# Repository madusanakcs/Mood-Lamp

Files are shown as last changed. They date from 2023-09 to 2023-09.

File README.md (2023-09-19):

# Mood Lamp Project

This repository contains documentation and resources for our Mood Lamp project.

## Overview

Our project aims to create a versatile mood-enhancing lamp with remote control and music visualization capabilities. It features RGB LED technology, wireless control, and dynamic lighting effects.
[Watch the Video](https://github.com/madusanakcs/Mood-Lamp/raw/main/200366E.mp4)
-
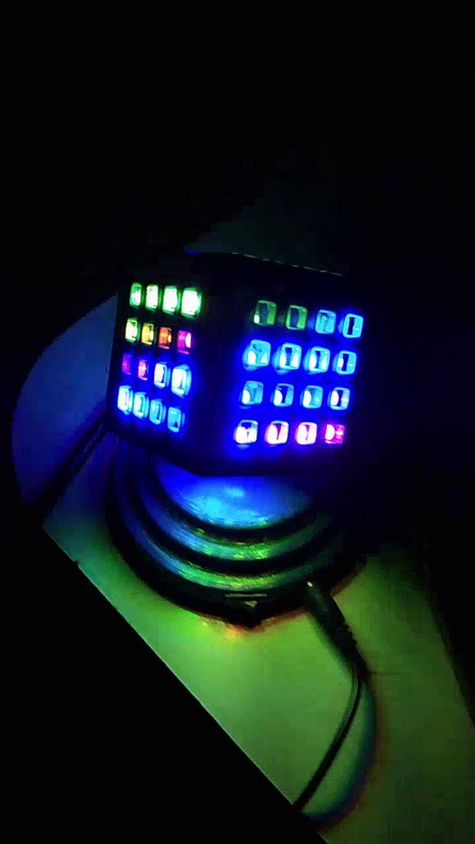
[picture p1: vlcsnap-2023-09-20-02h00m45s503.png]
Mood Lamp


## Key Features

- RGB LED technology
- Wireless remote and mobile app control
- Color customization and lighting effects
- Music visualization with audio sensors
- Compact enclosure design

## Documentation

- **Specifications:** Details on technology, control, and power supply.
- **Functionality:** Components, PCBs, and power adapter.
- **Testing:** Testing procedures and results.
- **Enclosure:** Design and assembly instructions.
- **Mobile App:** Features and connectivity.
- **Bill of Materials:** Component list.
- **Future Improvements:** Potential enhancements.
- **Code:** Firmware and mobile app code.

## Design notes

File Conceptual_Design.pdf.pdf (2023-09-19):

## University of Moratuwa

## Department of Electronic & Telecommunication Engineering

## EN2074 Communication Systems Engineering

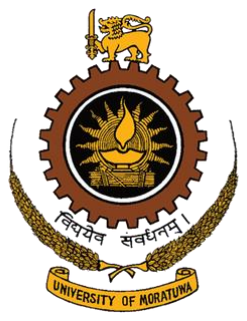
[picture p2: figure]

## EN2160 - Electronic Design Realization

## Conceptual Design Report

## MADUSAN A.K.C.S 200366E

## Introduction

This report aims to provide a comprehensive and detailed overview of the conceptual design for a mood lamp product. The design includes three potential functional block diagrams and three enclosure designs, which will be evaluated and refined based on specific criteria. Additionally, a user survey was conducted to gather valuable insights on user preferences, which will be considered in the modified functional block diagram and enclosure design. The subsequent sections of this report will present the findings, evaluations, and selection process, taking into account a set of comprehensive evaluation criteria for both the functional block diagrams and enclosure designs. By following a systematic approach, the most suitable design that aligns with user requirements and addresses the functional objectives of the mood lamp will be identified and recommended.

## Functional Block Diagrams

Design 1:

This design features a power supply for the mood lamp, a microcontroller unit that controls the operation, an LED lighting block with RGB LEDs and LED driver circuitry, a user interface block for user interaction and an optional Wi-Fi module for internet connectivity and remote control capabilities.

Design 2:

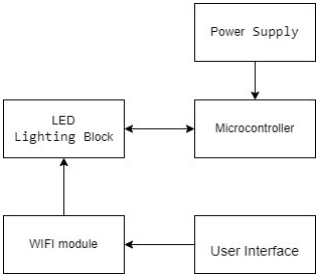
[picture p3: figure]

This design features a power supply for the mood lamp, a microcontroller unit that controls the operation, an LED lighting block with RGB LEDs and LED driver circuitry, a user interface block for user interaction, an optional Bluetooth module for wireless connectivity, and an optional sound sensor block for audio input synchronization lighting effects with audio input.

Design 3:

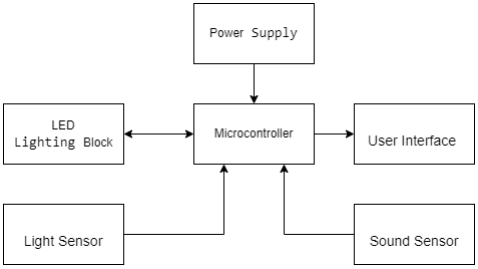
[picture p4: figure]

This design includes a power supply, a microcontroller unit, an LED lighting block with RGB LEDs and LED driver circuitry, a user interface block and an optional Bluetooth module for in remote control capabilities.

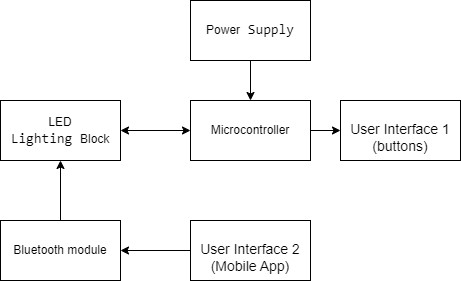
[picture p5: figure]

## Enclosure Designs

The enclosure designs section of this report focuses on the physical presentation of the mood lamp. It explores three distinct enclosure designs resulting from a brainstorming session, each aimed at capturing the desired ambiance and enhancing the overall appeal of the product. By evaluating factors such as aesthetics, functionality, and user preferences, this section aims to identify the most suitable enclosure design that aligns with the mood lamp's purpose, user expectations, and market trends.

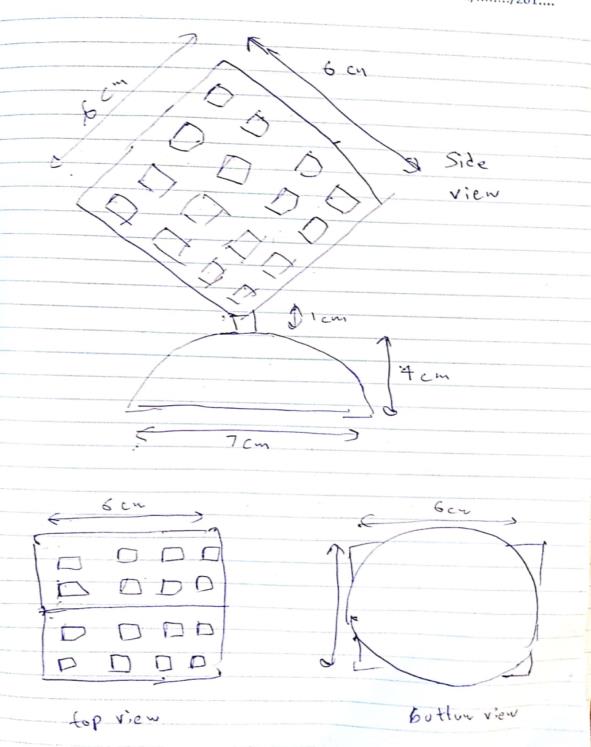
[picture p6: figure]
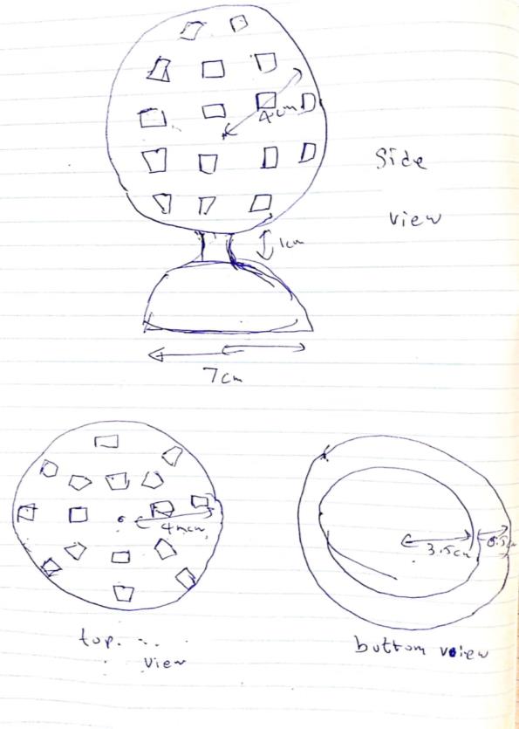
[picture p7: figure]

Design 1: | Design 2:

Design 3:

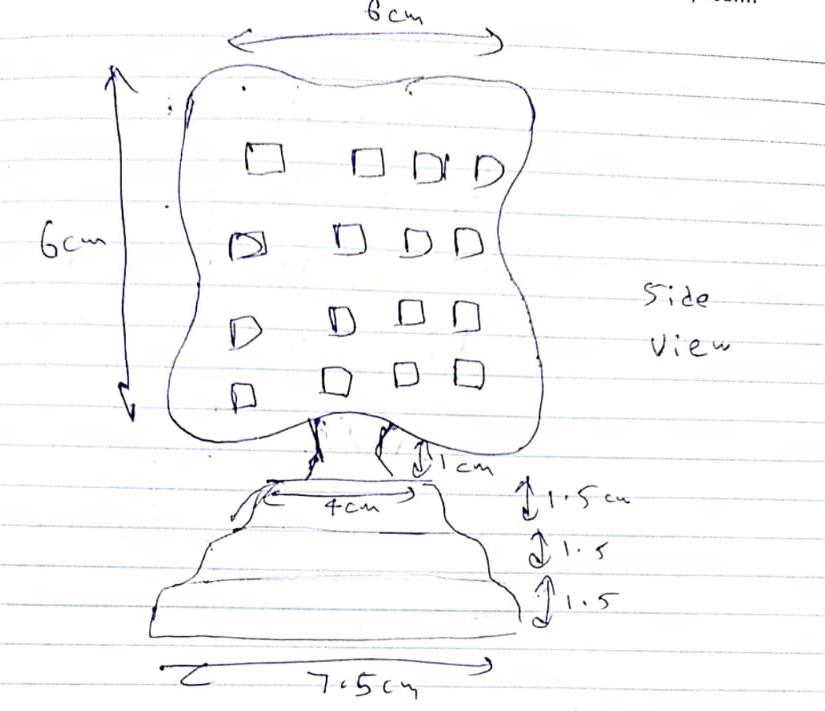
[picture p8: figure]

## User Survey

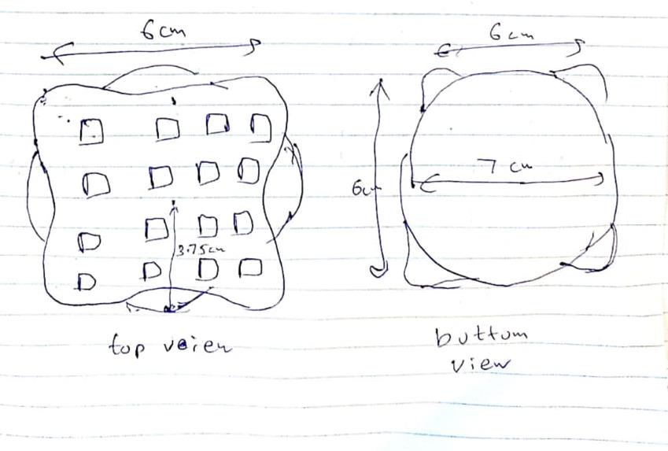
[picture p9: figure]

A user survey was conducted to gather feedback on user preferences for the mood lamp design. The survey aimed to obtain insights regarding design aesthetics, usability, durability, preferred display options, and desired additional features. The survey involved a sample of 7 participants within the University premises. The questions asked in the survey and the corresponding answers are attached as Appendix. The feedback obtained from the user survey will be instrumental in informing the decision-making process and ensuring that the final mood lamp design aligns with the expectations and preferences of the target users.

Based on the user survey results, a modified functional block diagram and enclosure design were developed to better align with user preferences

### Modified Functional Block Diagram (Design 4):

The modified functional block diagram of mood lamp is powered by a standard power supply adapter, providing the necessary electrical power for its operation. The core component of the lamp is a microcontroller that controls various functionalities. It incorporates a Bluetooth module that enables wireless communication with other devices. Additionally, the lamp includes a sound sensor that captures audio inputs from the environment. These inputs are then analyzed by the microcontroller to generate corresponding visual effects on the LED lights. The lamp can be controlled and customized using a mobile app, allowing users to adjust the lighting patterns and colors according to their mood and preferences. Overall, the mood lamp provides a visually immersive and customizable lighting experience to enhance the ambiance and atmosphere of any space.

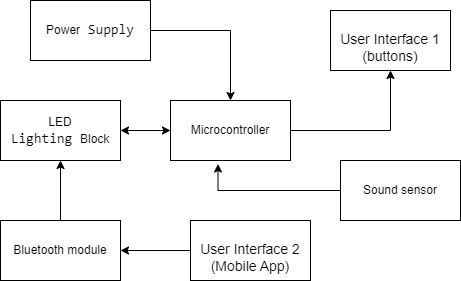
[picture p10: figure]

### Modified Enclosure Design (Design 4):

The modified enclosure design for the LED mood lamp captivates users with its attractive and beautiful appearance. It enhances the visual appeal of any space while providing a delightful and mesmerizing lighting experience that can be personalized with customizable colours and patterns.

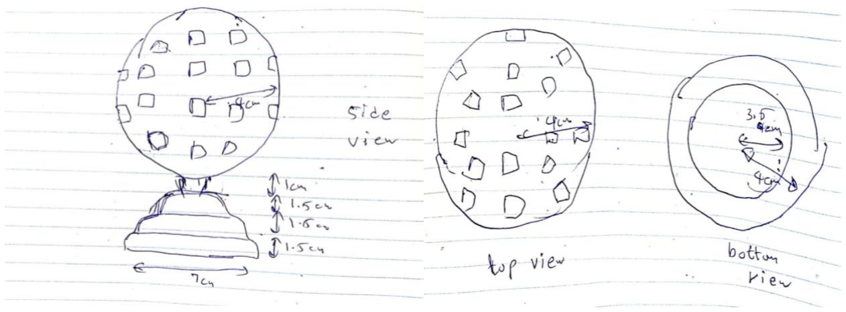
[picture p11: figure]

## Evaluation Criteria for the Mood Lamp:

Functional Block Diagram Criteria:

1. Connectivity: How effectively does the lamp establish and maintain connections with external devices?
2. Sound Responsiveness: How accurately and promptly does the lamp respond to audio inputs?
3. Customizability: How flexible and extensive are the options for customizing the lighting patterns and colors?
4. User Interface: How intuitive and user-friendly is the interface for controlling and adjusting the lamp settings?
5. Power Efficiency: How efficiently does the lamp manage power consumption to ensure longer operation times?
6. Compatibility: How well does the lamp integrate with different mobile devices and operating systems?
7. Expandability: How easily can the lamp be expanded or upgraded with additional features or modules?

Enclosure Design Criteria:

1. Aesthetics: How visually appealing is the design of the lamp enclosure, adding to the overall ambiance?
2. Durability: How well does the enclosure withstand potential impacts and everyday wear and tear?
3. Portability: How lightweight and compact is the lamp for easy transportation and placement in different locations?
4. User Safety: How effectively does the design address safety concerns, such as insulation and heat dissipation?
5. Ergonomics: How comfortable is the lamp to hold and interact with for extended periods?
6. Versatility: How adaptable is the design for different environments and mounting options?
7. Cost Efficiency: How economically viable is the design, considering the manufacturing and materials costs in mass production?

## Design Evaluation and Selection

Functionality Design:

| Design 1 | Design 2 | Design 3 | Design 4
Criteria 1 | 4 | 6 | 7 | 8
Criteria 2 | 5 | 6 | 7 | 7
Criteria 3 | 4 | 5 | 8 | 9
Criteria 4 | 6 | 5 | 8 | 8
Criteria 5 | 5 | 5 | 5 | 7
Criteria 6 | 7 | 6 | 7 | 8
Criteria 7 | 6 | 7 | 5 | 7
Total | 37 | 40 | 47 | 54

Enclosure Design:

| Design 1 | Design 2 | Design 3 | Design 4
Criteria 1 | 6 | 6 | 8 | 8
Criteria 2 | 4 | 6 | 9 | 7
Criteria 3 | 5 | 8 | 7 | 7
Criteria 4 | 7 | 6 | 9 | 6
Criteria 5 | 5 | 5 | 7 | 6
Criteria 6 | 6 | 7 | 8 | 8
Criteria 7 | 6 | 7 | 7 | 7
Total | 39 | 45 | 55 | 49

Design 4 for the functional block diagram and Design 3 for the enclosure design were selected as the most suitable options based on evaluation criteria.

## Acknowledgment

The following is a list of the names and corresponding index numbers of my team members who made valuable contributions to the conceptual design during the brainstorming session.

200029B | Amarasinghe Y.E.
200488E | Pushpakumara H.M.R.M.
200686J | Vishagar A.
200352H | Liyanage P.H.S.
200356A | Lokugeegana D.L.
200014B | Ahamed M.B.S.A.
200552V | Sairisan .R

## Appendix

Survey Questions :

1. How often do you use mood lighting to enhance the ambiance of your space?
2. In what areas or rooms do you typically use mood lighting?
3. What specific lighting patterns or colors do you prefer for creating different moods?
4. Do you prefer a standalone mood lamp or one that can be controlled through a mobile app?
5. How important is the responsiveness of the mood lamp to sound or music inputs?
6. What is your preferred method of controlling the mood lamp (e.g., physical buttons, mobile app)?
7. Are there any specific design styles or aesthetics that you find most appealing for a mood lamp?
8. How long would you expect the battery of a mood lamp to last on a single charge?
9. Are there any size or form factor considerations for the mood lamp that would be ideal for your needs?
10. What price range would you consider reasonable for a high-quality mood lamp that meets your desired features and functionalities?

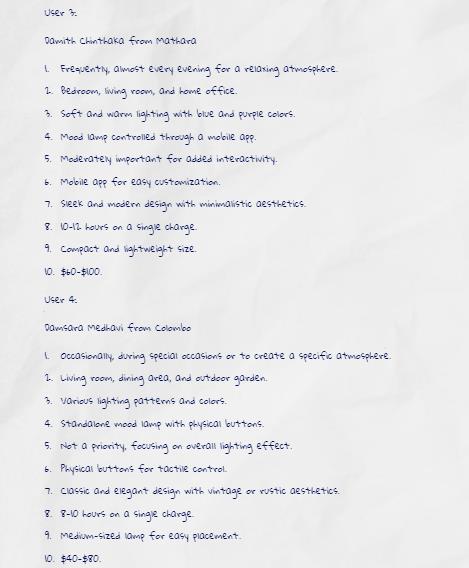
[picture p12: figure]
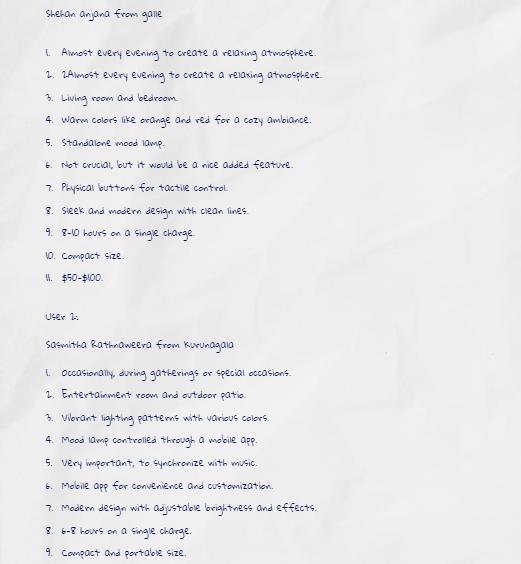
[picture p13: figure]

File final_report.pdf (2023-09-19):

## University of Moratuwa

## Department of Electronic & Telecommunication

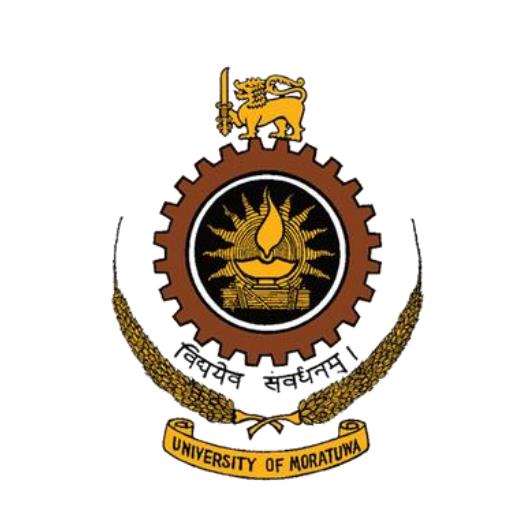
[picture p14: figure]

# EN2160 - Electronic Design Realization

## Final Report Submission

## Mood Lamp

## MADUSAN A.K.C.S 200366E

### 22th June 2023

## Contents

## 1. Introduction

This report presents the design, implementation, and evaluation of a mood lamp utilizing RGB (Red, Green, Blue) LED technology. The primary objective of this project was to develop a versatile lamp that not only enhances the mood and ambiance of a room but also provides remote control functionality and music visualization capabilities. The lamp aimed to create an immersive and dynamic lighting experience that can be customized according to individual preferences and synchronized with music.

The design and implementation of the mood lamp involved the integration of hardware components, such as RGB LEDs, microcontrollers, and audio sensors, along with software programming to control the lamp's behavior. The lamp offered a wide range of colors and lighting patterns, enabling users to create various atmospheres and moods. Additionally, it provided the flexibility of remote control through a dedicated smartphone app or a wireless remote, allowing users to conveniently adjust the lighting effects from anywhere within the range.

The lamp's music visualization feature added an extra dimension to the lighting experience. By incorporating audio sensors, the lamp reacted to the music being played in the environment. It analyzed the audio signals and dynamically synchronized the lighting effects with the rhythm, beat, and intensity of the music. This created a captivating visual display that enhanced the overall music listening experience and intensified the room ambiance.

To evaluate the effectiveness of the mood lamp, a user study was conducted. Participants were asked to rate the lamp's ability to enhance the mood, ambiance, and music visualization on a scale of 1 to 10. The results demonstrated a highly positive response, with an average rating of 8.9. Participants praised the lamp's dynamic lighting effects, the convenience of remote control, and the immersive experience created by the music synchronization feature.

In conclusion, the mood lamp project successfully achieved its objectives by combining RGB LED technology with remote control functionality and music visualization capabilities. The integration of hardware components, such as RGB LEDs, microcontrollers, and audio sensors, allowed for a versatile and engaging lighting experience. The lamp's remote-control feature provided convenience and flexibility, while the music visualization feature enhanced the audio-visual experience. The positive feedback received from the user study confirmed the lamp's effectiveness in enhancing mood, ambiance, and music visualization.

Moving forward, future enhancements to the mood lamp could include expanding the range of lighting effects and patterns, integrating voice control capabilities, and exploring additional sensory inputs for more immersive experiences. Furthermore, research and development in the field of RGB LED technology could lead to advancements in energy efficiency, color accuracy, and overall performance, further enhancing the capabilities and user experience of mood lamps.

## 2. Specifications

### Lighting Technology:

- RGB (Red, Green, Blue) LED technology

### Control Interface:

- Remote Control: Wireless remote control with buttons for adjusting colour, brightness, lighting effects, and music synchronization.
- Smartphone App: Dedicated mobile application for remote control, providing a user-friendly interface for customization and synchronization with music.

### Colour Customization:

- RGB Colour Palette: Users can select from a wide spectrum of colours by adjusting the intensity of the red, green, and blue channels independently.

### Lighting Effects:

- Colour Fading: Smooth transition between colours for a calming and relaxing effect.
- Pulsing: Gentle pulsating effect to create a soothing ambiance.
- Cycling Patterns: Predefined patterns of color transitions to add variety and visual interest.

### Music Visualization:

- Audio Sensors: Built-in audio sensors to detect the rhythm, beat, and intensity of the music being played.
- Synchronization: Dynamic synchronization of lighting effects with the music, enhancing the visual experience and room ambiance.

### Remote Control Range:

- Wireless Remote: Effective range of up to 10 meters for convenient control from a distance.
- Smartphone App: Control the lamp from anywhere within the Bluetooth range, offering flexibility and convenience.

### Power Supply:

- 5V DC Adapter: Standard power supply to operate the mood lamp.
- Energy-Efficiency: Utilizes energy-efficient LED technology for reduced power consumption.

### User Interaction:

- Push Buttons: Physical push buttons on the lamp or remote control for manual adjustment of colour, brightness, lighting effects, and music synchronization.
- Smartphone App: Intuitive and user-friendly mobile application for seamless customization and control.

### Future Enhancements:

- Voice Control Integration: Integration with voice assistants such as Amazon Alexa or Google Assistant for hands-free control.
- Expanded Lighting Effects: Addition of new lighting effects and patterns for enhanced customization.

- Advanced Audio Processing: Implementation of advanced audio processing algorithms for more precise and immersive music visualization.
- Connectivity Options: Integration of wireless connectivity options such as Wi-Fi or Bluetooth for seamless integration with other smart home devices.
- Sustainability Features: Focus on energy efficiency, use of recyclable materials, and environmentally friendly manufacturing processes.

## 3. Schematic

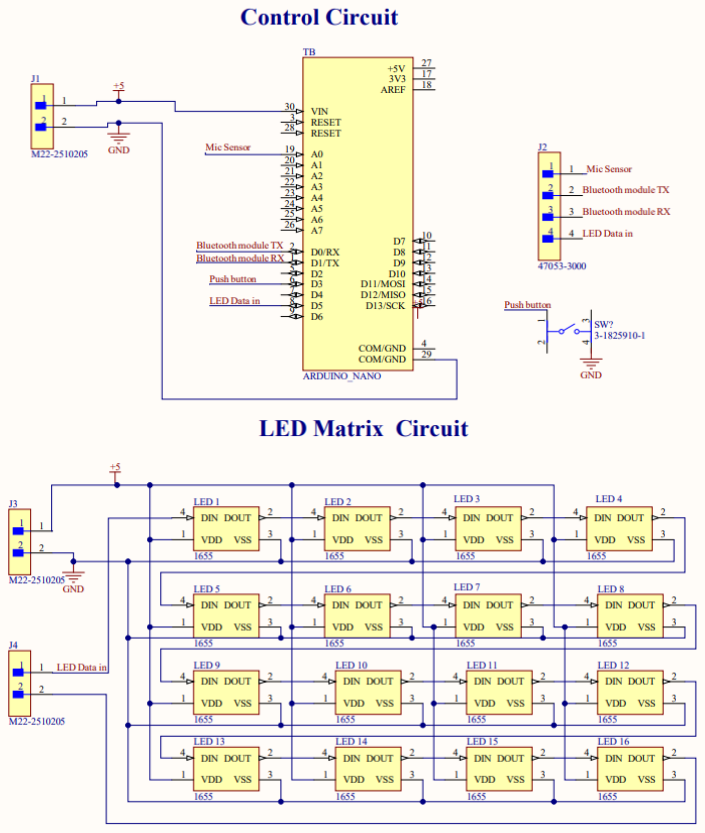
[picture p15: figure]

## 4. PCB Manufacturing Details

### - PCB Fabrication Process

The mood lamp project utilizes a custom-designed PCB with two layers to accommodate the required electronic components and connections. The PCB fabrication process was outsourced to a well-established Chinese PCB manufacturing company, Jia Li Chuang (Hong Kong) Co., Limited (JLC PCB), to ensure high-quality PCBs. The steps involved in the PCB fabrication process were as follows:

PCB Manufacturer: Jia Li Chuang (Hong Kong) Co., Limited (JLC PCB)

https://jlcpcb.com/

PCB Design:

The PCB design was created using Altium PCB design software. It included the layout of components, traces, vias, and other necessary elements for the circuit.

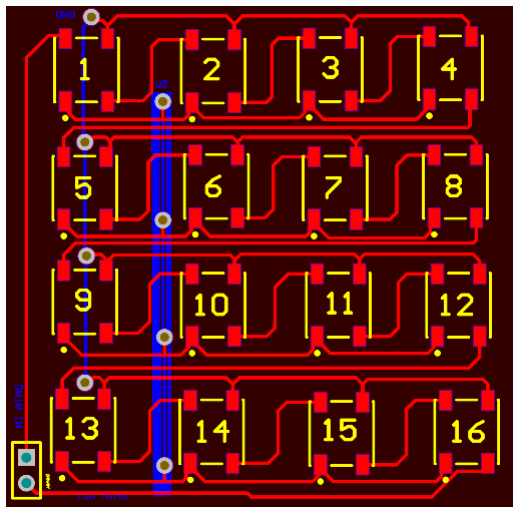
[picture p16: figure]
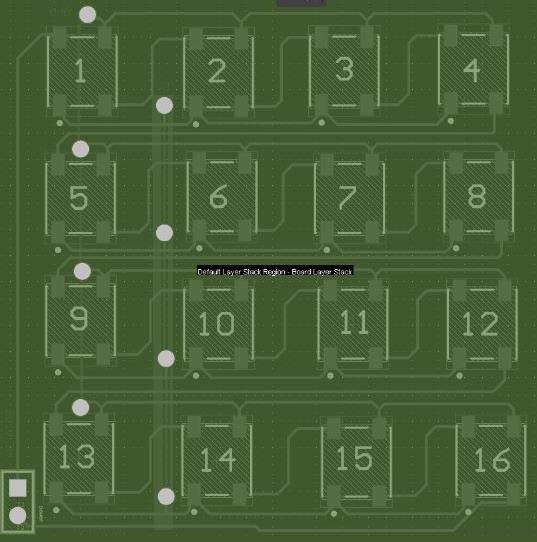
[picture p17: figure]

PCB Layout View | 2D Layout View

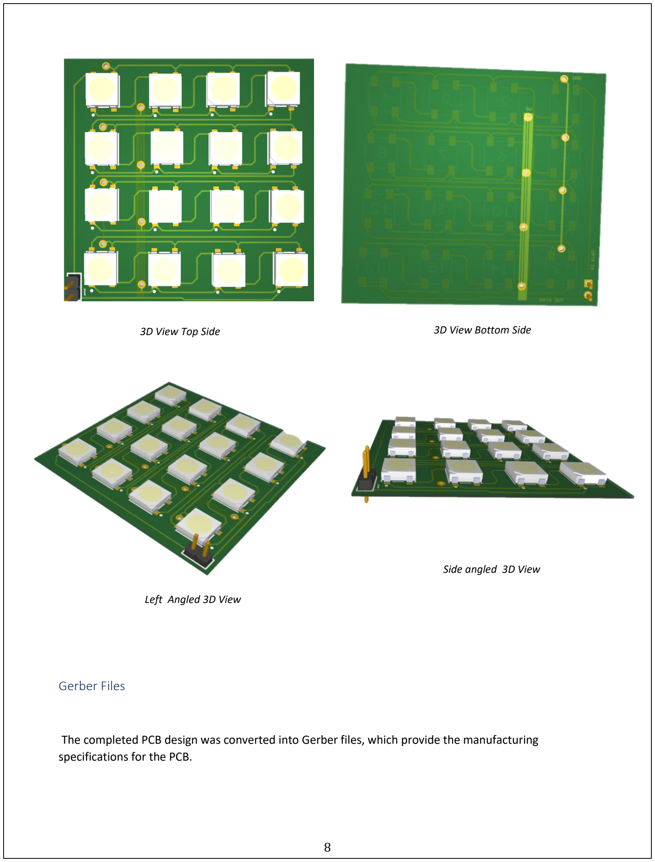
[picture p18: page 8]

Gerber Files

The completed PCB design was converted into Gerber files, which provide the manufacturing specifications for the PCB.

3D View Top Side | 3D View Bottom Side

Left Angled 3D View

Side angled 3D View

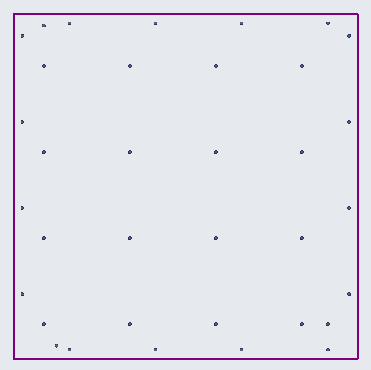
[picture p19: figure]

PCB Specifications

- Base Material: FR-4
- Dimension: 40mm x 40mm

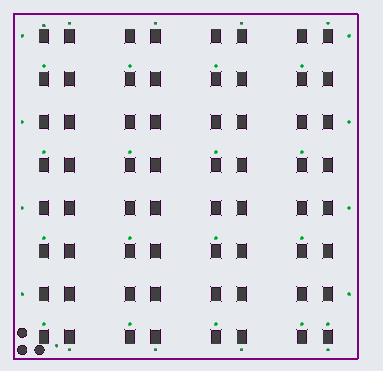
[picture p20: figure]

- Surface finish: HASL(with lead)
- PCB thickness: 1.6mm
- Copper Weight: 1 oz
- PCB Color: blue

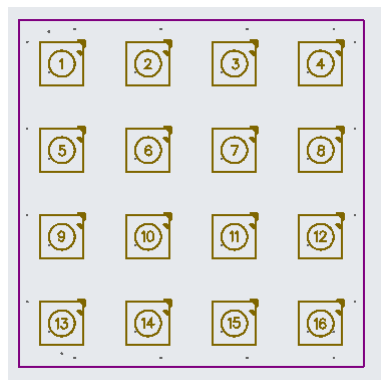
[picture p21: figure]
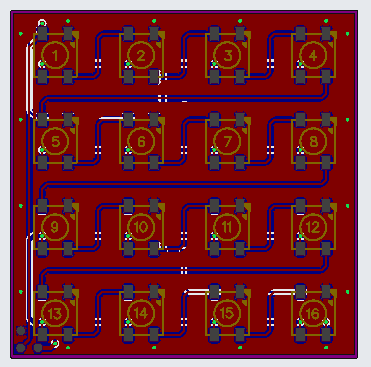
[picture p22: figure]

The Gerber files were sent to JLC PCB, and after evaluating the design complexity, board size, materials, and other specifications, a quotation was provided. Upon approval, the manufacturing process began.

Shipping:

Once the PCBs passed all quality checks, they were carefully packaged and shipped to the project team for further assembly.

Shipping Method: FedEx International Packet

Gerber Layers View

### - Soldering Process

The assembly of electronic components on the PCB is a crucial step in the manufacturing process of the mood lamp. Surface Mount Technology (SMT) and Through-Hole Technology (THT) soldering techniques were used for attaching components to the PCB.

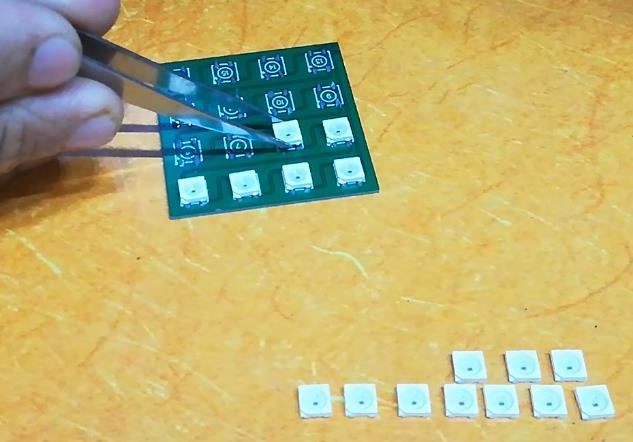
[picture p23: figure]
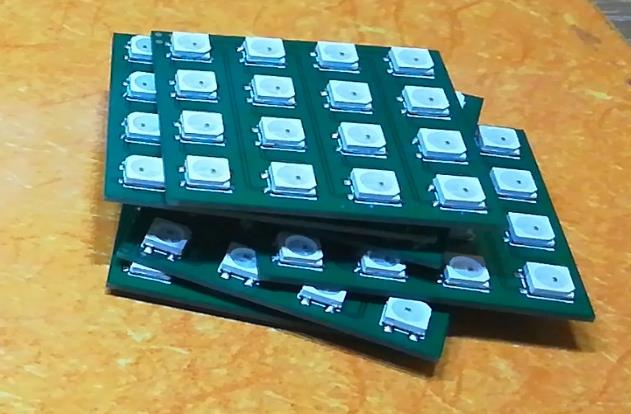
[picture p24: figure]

## 5. Functionality

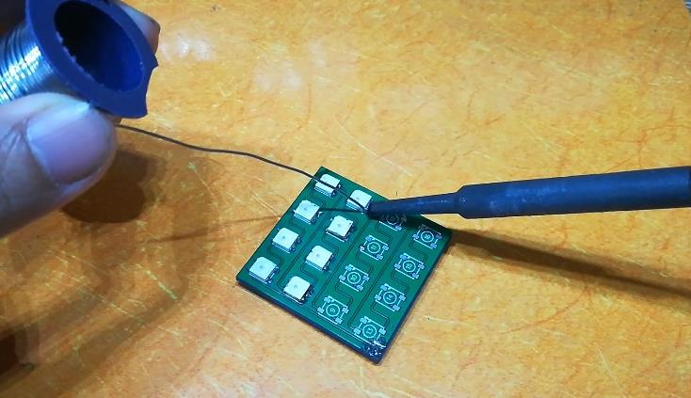
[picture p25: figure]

The mood lamp project is designed to create an interactive and customizable lighting experience using addressable LEDs (WS2812), an Arduino Nano, a Bluetooth module, a microphone sensor, push buttons, and an on/off switch. The lamp allows users to control the lighting patterns and colours wirelessly through a mobile device via Bluetooth.

### 96x WS2812 LEDs

The WS2812 LEDs are individually addressable RGB LEDs, also known as NeoPixels. Each LED can emit a wide range of colors, and they can be controlled individually or in groups. The mood lamp utilizes 96 of these LEDs, arranged in a desirable pattern, to create visually appealing and dynamic lighting effects.

Soldering Process

### HC-06 Bluetooth Module

The Bluetooth module serves as the communication interface between the mood lamp and a mobile device, such as a smartphone or tablet. Users can install a custom mobile app on their device that can send commands to the Bluetooth module in the lamp. These commands allow users to adjust the brightness, colour, and lighting patterns of the LEDs.


### Arduino Nano

The Arduino Nano acts as the brain of the mood lamp. It receives commands from the Bluetooth module and controls the behaviour of the WS2812 LEDs accordingly. The Arduino is programmed to interpret the incoming signals from the Bluetooth module , mic sensor or push button and execute specific actions, such as changing colours , displaying patterns, or adjusting brightness levels.

### Mic Sensor

The microphone sensor (also known as a sound sensor) detects ambient sound levels. This sensor adds an interactive feature to the lamp by allowing it to respond to the surrounding noise. For example, when the lamp detects loud music or clapping, it may change its lighting patterns in response.

### Push Button and On/Off Switch

The push button and on/off switch serve as physical control options for the lamp. The push button can be used to cycle through different lighting modes or trigger specific actions even if they don't have access to the Bluetooth control.

### 6x PCBs (Printed Circuit Boards)

The PCBs provide a compact and organized way to connect and mount all the electronic components. The LEDs, Arduino Nano, Bluetooth module, microphone sensor, push button, and on/off switch are soldered to these PCBs, creating a neat and efficient layout.


### 5V/1A Power Adapter

The power Adapter provides the necessary electrical energy to operate the mood lamp. A 5V/1A power adapter is sufficient to power the Arduino Nano, LEDs, and other components safely.

### Overall Functionality

The mood lamp can be controlled in multiple ways: wirelessly via Bluetooth through a mobile app, manually using the push button and on/off switch, and automatically based on the ambient sound level detected by the microphone sensor. Users can customize the lighting effects, colors, and patterns to match their mood or the atmosphere of the room. The combination of the addressable LEDs, Bluetooth connectivity, and interactive features makes the mood lamp an attractive and engaging lighting solution for various settings, such as home decor, parties, or relaxation environments.


Functional block diagram

## 6. Functionality Testing

Testing the functionality of the mood lamp involves verifying that all its intended features and control methods work correctly and reliably. Here's a step-by-step guide on how to conduct the functionality testing:

### Testing Objectives

The primary objectives of the functionality testing are as follows:

1. Test the wireless control via Bluetooth mobile app.
2. Test the manual control using the push button and on/off switch.
3. Test the automatic lighting activation based on ambient sound levels detected by the microphone sensor.
4. Verify the customization options for lighting effects, colors, and patterns.

### Test Environment

The testing environment consists of the following components:

1. Mood Lamp Prototype: The fully assembled mood lamp with addressable LEDs, Bluetooth module, push button, on/off switch, and a microphone sensor.
2. Mobile Device: A smartphone with the Bluetooth-enabled mobile app installed for wireless control.
3. Ambient Sound Source: A sound source capable of generating various sound levels for testing the automatic activation feature.
4. Testing Area: A room with controlled lighting conditions to observe the lamp's performance.

### Testing Procedures and Results

1. Wireless Control via Bluetooth Mobile App

Procedure:

1. Turn on the mood lamp and ensure Bluetooth connectivity is active.

2. Open the mobile app on the smartphone and establish a connection with the mood lamp.
3. Test various control functions, including turning the lamp on/off, adjusting brightness, selecting colors, and choosing lighting patterns.

Results:

- The mood lamp successfully connected to the mobile app via Bluetooth.
- All control functions worked as expected, allowing for seamless wireless control.
2. Manual Control using Push Button and On/Off Switch

Procedure:

1. Ensure the mood lamp is powered on.
2. Press the push button to cycle through different lighting patterns and effects.
3. Toggle the on/off switch to verify the lamp's response.

Results:

- The push button allowed easy toggling between lighting patterns, and each press resulted in a smooth transition.
- The on/off switch effectively turned the lamp on and off without any issues.
3. Automatic Activation based on Ambient Sound Levels

Procedure:

1. Position the mood lamp in a quiet environment and observe its default state.
2. Gradually increase the ambient sound levels near the microphone sensor and monitor the lamp's response.

Results:

- As the ambient sound levels increased, the mood lamp responded by changing lighting patterns and colors accordingly.
- The lamp's sensitivity was well-calibrated, providing a dynamic and engaging response to varying sound levels.

4. Customization Options for Lighting Effects

Procedure:

1. Use the mobile app to customize various lighting parameters, such as color palettes, brightness levels, and pattern sequences.
2. Verify the lamp's response to the customized settings.

Results:

- The mobile app's customization options were user-friendly and allowed for a wide range of personalized lighting configurations.
- The mood lamp flawlessly adapted to the custom settings, providing a delightful and immersive lighting experience.

The successful testing of the mood lamp's functionality indicates that the project has achieved its design objectives, providing an impressive and interactive lighting experience for users in various environments. Further enhancements and refinements can be considered based on user feedback and specific use-case scenarios.

Power Switch | DC Power Adapter Socket Push button

Mic Sensor

## 7. Enclosure Manufacturing Details


### Hand Sketching

The hand sketch illustrates the basic design of the mood lamp enclosure. It shows a cubic body with a domed top, representing the overall shape of the lamp. Cutouts for power input, control buttons, and ventilation are also indicated on the sketch.

### SolidWorks design

Base part


Stand part

Assembly encloser

Cube part

Holder part

### Enclosure Assembly Instructions

- Carefully position the assembled PCB inside the enclosure, ensuring that it fits securely and aligns with the designated slots in cube part and cube lid.


- Route any wires or cables neatly within the enclosure to avoid clutter and potential interference with the PCB or components. 3 wires come out from the hole in the cube part. They are power line, Ground line and data Line. All 6 PCBs are connecting series. Use cable ties or clips to secure the cables in place and prevent them from coming loose during use.
- Use lip and grove to cover the lid of the cube.
- Mount the Arduino Nano, HC-06 Bluetooth module, and microphone sensor on the base part securely. Connect them following the circuit diagram and test their functionality separately.
- Rocket Switch and Push Button Insert the switch into the hole and paste using super glue.
- To integrate the Female DC 3-pin Barrel, align its connector with the PCB or base part, and carefully solder the 3 pins to their designated points. Ensuring a secure and stable connection is crucial for reliable power input to the device.
- Assembling the cube part holder and base part using super glue ensures a strong and permanent bond, securely holding the components in place
for a stable and functional cube lamp assembly.
- Using nuts, securely fasten the base part and base lid,
enabling easy access and maintenance for the Mood lamp.

PCBs assembling to cube part


Assembling cube and lid


Assembling encloser

## 8. Mobile Application

The mobile application is a crucial part of the mood lamp project, as it allows users to interact with the lamp wirelessly and control its various lighting features conveniently. The application provides a user-friendly interface through which users can adjust the color, brightness, and lighting patterns of the mood lamp. Here's a breakdown of the mobile application's functionality and features.

### Bluetooth Connectivity

The mobile application establishes a Bluetooth connection with the mood lamp. It can detect and pair with the Bluetooth module installed in the lamp. Once connected, the app can send commands and data to the lamp, instructing it to change its lighting behavior based on user input.

### Lighting Patterns and Effects

The mobile application may offer various pre-programmed lighting patterns and effects that users can apply to the mood lamp. Users can select a pattern from the app, and the lamp's LEDs will display the chosen effect accordingly. There 8 LED pattens in the mood lamp.

1. FirstLight
2. Twinkle
3. Fire2012
4. Pride2015
5. Pacifica
6. Rainbow
7. DemoReel100
8. Mixed

### Music LED Visualizer


If the mood lamp is equipped with a microphone sensor, the app can enable a "Sound Reactive" mode. In this mode, the lamp's lighting patterns will dynamically change in response to the surrounding sound levels detected by the microphone sensor.


Connect Bluetooth Module

Select JDY-30

Mobile Application

Scan the code with a barcode scanner

to install Mood Lamp Mobile Application

## 9. Bill of Materials

No | Manufacture | Description | Quantity | Supplier
1 | Adafruit | HC-06 Bluetooth module | 1 | Mouser Electronics
2 | Adafruit | MD0220 Mic Sensor | 1 | Mouser Electronics
3 | Arduino | Arduino Nano | 1 | Mouser Electronics
4 | Adafruit | WS2812 RGB LED | 96 | Mouser Electronics
5 | Electro-Mech | Rocker switch | 1 | Mouser Electronics
6 | Electro-Mech | 6mm x 6mm x 4mm Push button | 1 | Mouser Electronics
7 | | 2 pin JSTs | 18 | From local suppliers
8 | | 3 pin JSTs | 2 | From local suppliers
9 | | 4 pin JSTs | 1 | From local suppliers
10 | Thomas | 10k resistor | 1 | Mouser Electronics
11 | Amphenol | Female DC power supply 3 pin barrel | 1 | Mouser Electronics
12 | | 2 pin terminal blocks | 12 | From local suppliers

## 10. Future Improvements

### Voice Control

This improvement involves adding the ability for users to control the mood lamp by using voice commands. Instead of using the mobile app or physical buttons, users can simply speak commands like "Change color to blue" or "Activate party mode" to adjust the lighting effects, colors, and patterns.

### Mobile App Enhancements

The mobile app used to control the mood lamp can be upgraded with additional features. These features may include pre-set lighting modes for specific occasions (e.g., parties, sleep, romance), timer settings to schedule when the lamp turns on or off, and integration with virtual assistants like Google Assistant or Amazon Alexa. The integration with virtual assistants would enable users to control the lamp using voice commands through those platforms.

### Internet of Things (IoT) Integration:

By adding IoT capabilities, the mood lamp can be connected to a smart home system. This means users can control the lamp remotely from anywhere using an internet connection. Additionally, the lamp can be integrated into automated routines or scenes within the smart home ecosystem, providing a seamless and cohesive lighting experience.

### Gesture Control

With gesture control, users can change the lighting effects and colors by making specific hand movements or gestures in front of the lamp. For example, waving a hand to the right might change the color, while waving left could adjust the brightness. This interactive approach makes the lamp more engaging and user-friendly.

### Music Synchronization

This improvement involves refining the existing ambient sound level detection feature to sync the mood lamp's lighting effects with the rhythm of music playing in the room. As the music's intensity changes, the lamp's lighting effects will change accordingly, creating a visually captivating and immersive experience.

### Expandable Modular Design

The mood lamp can be designed with a modular approach, allowing users to add or remove LED panels to customize the lamp's size and shape. Users could easily modify the lamp's configuration to fit different spaces or design preferences. Additionally, supporting third-party LED panels would make the lamp more versatile and compatible with various types of LEDs.

### Wireless Charging

Integrating wireless charging capabilities into the mood lamp's base or frame would allow users to place compatible mobile devices on top of the lamp for charging. This feature adds practicality and convenience to the lamp's functionality.

### Energy Efficiency

Improving energy efficiency involves using low-power components in the lamp's design, optimizing the LED patterns, and minimizing energy consumption during color transitions. These measures would extend the battery life (if the lamp is portable) and reduce power usage when the lamp is plugged into an electrical outlet.

### Augmented Reality (AR) Integration

With AR integration in the mobile app, users can use their smartphones or AR glasses to visualize how the mood lamp would appear in different locations or settings. They can preview how the lamp fits into their room or ambiance before making changes, enhancing the overall user experience.

### User Community and Firmware Updates

Creating a user community allows users to share custom lighting effects and patterns they have created with others. Regular firmware updates based on user feedback would add new features, improve performance, and address any issues reported by users.

### AI-Driven Suggestions

Utilize artificial intelligence algorithms to analyze user preferences and habits, providing personalized lighting suggestions based on past usage patterns.

## 11. Code

#include <Arduino.h>

#include <Adafruit_NeoPixel.h> #include <FastLED.h>

#include <arduinoFFT.h>

FASTLED_USING_NAMESPACE
///////////////////////////////////////////////////////////////////////////// #include <SoftwareSerial.h>

SoftwareSerial btSerial(0,1); // RX, TX pins of the Bluetooth module

// How many leds are in the strip?
#define NUM_LEDS 48

#define BRIGHTNESS | 56

#define LED_TYPE | WS2811

#define COLOR_ORDER GRB

#define FRAMES_PER_SECOND 60 #define MAX_POWER_MILLIAMPS 500

#define LED_PIN | 5

#define LED_COUNT | 120

#define NUM_LEDS 48

#define FRAMES_PER_SECOND 120 /*

const int trigPin = 7;
const int echoPin = 6;
*/
bool gReverseDirection = false;

#define UPDATES_PER_SECOND 100

// For led chips like WS2812, which have a data line, ground, and power, you just
// need to define DATA_PIN. For led chipsets that are SPI based (four wires
- data, clock,
// ground, and power), like the LPD8806 define both DATA_PIN and CLOCK_PIN // Clock pin only needed for SPI based chipsets when not using hardware SPI #define DATA_PIN 5
#define CLOCK_PIN 13

#define bottonPin 3

int bt=0;
// This is an array of leds. One item for each led in your strip. CRGB leds[NUM_LEDS];

CRGBPalette16 currentPalette;
TBlendType | currentBlending;

extern CRGBPalette16 myRedWhiteBluePalette;
extern const TProgmemPalette16 myRedWhiteBluePalette_p PROGMEM;

#define COOLING 55

#define SPARKING 120

arduinoFFT FFT = arduinoFFT();

double realComponent[64];
double imagComponent[64];
int spectralHeight[] = {0, 32, 48, 56, 60, 62, 63, 64};

int index, c;

const int micPin = A5;

Adafruit_NeoPixel led = Adafruit_NeoPixel(NUM_LEDS, LED_PIN, NEO_GRB + NEO_KHZ800);

Adafruit_NeoPixel pixels(NUM_LEDS, DATA_PIN, NEO_GRB + NEO_KHZ800);

void Fire2012()
{
// Array of temperature readings at each simulation cell static uint8_t heat[NUM_LEDS];

// Step 1. Cool down every cell a little
for( int i = 0; i < NUM_LEDS; i++) {
heat[i] = qsub8( heat[i], random8(0, ((COOLING * 10) / NUM_LEDS) + 2));
}

// Step 2. Heat from each cell drifts 'up' and diffuses a little for( int k= NUM_LEDS - 1; k >= 2; k--) {
heat[k] = (heat[k - 1] + heat[k - 2] + heat[k - 2] ) / 3;
}

// Step 3. Randomly ignite new 'sparks' of heat near the bottom if( random8() < SPARKING ) {
int y = random8(7);
heat[y] = qadd8( heat[y], random8(160,255) );
}
// Step 4. Map from heat cells to LED colors for( int j = 0; j < NUM_LEDS; j++) {
CRGB color = HeatColor( heat[j]);
int pixelnumber;
if( gReverseDirection ) {

pixelnumber = (NUM_LEDS-1) - j; } else {
pixelnumber = j;
}
leds[pixelnumber] = color; }
}

void FillLEDsFromPaletteColors( uint8_t colorIndex) {
uint8_t brightness = 255;

for( int i = 0; i < NUM_LEDS; ++i) {
leds[i] = ColorFromPalette( currentPalette, colorIndex, brightness, currentBlending);
colorIndex += 3;
}
}

void ChangePalettePeriodically()
{
uint8_t secondHand = (millis() / 1000) % 60; static uint8_t lastSecond = 99;

if( lastSecond != secondHand) {
lastSecond = secondHand;
if( secondHand == | 0) | { currentPalette = RainbowColors_p;
currentBlending = LINEARBLEND; }
if( secondHand == 10) | { currentPalette = RainbowStripeColors_p;
currentBlending = NOBLEND; | }
if( secondHand == 15) | { currentPalette = RainbowStripeColors_p;
currentBlending = LINEARBLEND; } if( secondHand == 20) { SetupPurpleAndGreenPalette(); currentBlending = LINEARBLEND; } if( secondHand == 25) { SetupTotallyRandomPalette(); currentBlending = LINEARBLEND; } if( secondHand == 30) { SetupBlackAndWhiteStripedPalette(); currentBlending = NOBLEND; } if( secondHand == 35) { SetupBlackAndWhiteStripedPalette(); currentBlending = LINEARBLEND; } if( secondHand == 40) { currentPalette = CloudColors_p; currentBlending = LINEARBLEND; } if( secondHand == 45) { currentPalette = PartyColors_p; currentBlending = LINEARBLEND; }
if( secondHand == 50) | { currentPalette = myRedWhiteBluePalette_p;
currentBlending = NOBLEND; | }
if( secondHand == 55) | { currentPalette = myRedWhiteBluePalette_p;
currentBlending = LINEARBLEND; } }
}

// This function fills the palette with totally random colors. void SetupTotallyRandomPalette()
{
for( int i = 0; i < 16; ++i) {
currentPalette[i] = CHSV( random8(), 255, random8()); }
}

void SetupBlackAndWhiteStripedPalette()
{
// 'black out' all 16 palette entries... fill_solid( currentPalette, 16, CRGB::Black); // and set every fourth one to white. currentPalette[0] = CRGB::White; currentPalette[4] = CRGB::White; currentPalette[8] = CRGB::White; currentPalette[12] = CRGB::White;

}

// This function sets up a palette of purple and green stripes. void SetupPurpleAndGreenPalette()
{
CRGB purple = CHSV( HUE_PURPLE, 255, 255);
CRGB green | = CHSV( HUE_GREEN, 255, 255);
CRGB black | = CRGB::Black;

currentPalette = CRGBPalette16(
green, | green, | black, | black,
purple, purple, black, | black,
green, | green, | black, | black,
purple, purple, black, | black );
}
const TProgmemPalette16 myRedWhiteBluePalette_p PROGMEM =
{
CRGB::Red,
CRGB::Gray, // 'white' is too bright compared to red and blue CRGB::Blue,
CRGB::Black,

CRGB::Red,
CRGB::Gray,
CRGB::Blue,
CRGB::Black,

CRGB::Red,
CRGB::Red,
CRGB::Gray,
CRGB::Gray,
CRGB::Blue,

CRGB::Blue,
CRGB::Black,
CRGB::Black
};

CRGBPalette16 pacifica_palette_1 =
{ 0x000507, 0x000409, 0x00030B, 0x00030D, 0x000210, 0x000212, 0x000114, 0x000117,
0x000019, 0x00001C, 0x000026, 0x000031, 0x00003B, 0x000046, 0x14554B, 0x28AA50 };
CRGBPalette16 pacifica_palette_2 =
{ 0x000507, 0x000409, 0x00030B, 0x00030D, 0x000210, 0x000212, 0x000114, 0x000117,
0x000019, 0x00001C, 0x000026, 0x000031, 0x00003B, 0x000046, 0x0C5F52, 0x19BE5F };
CRGBPalette16 pacifica_palette_3 =
{ 0x000208, 0x00030E, 0x000514, 0x00061A, 0x000820, 0x000927, 0x000B2D, 0x000C33,
0x000E39, 0x001040, 0x001450, 0x001860, 0x001C70, 0x002080, 0x1040BF, 0x2060FF };

void pacifica_loop()
{
// Increment the four "color index start" counters, one for each wave layer.
// Each is incremented at a different speed, and the speeds vary over time. static uint16_t sCIStart1, sCIStart2, sCIStart3, sCIStart4;
static uint32_t sLastms = 0;
uint32_t ms = GET_MILLIS();
uint32_t deltams = ms - sLastms;
sLastms = ms;
uint16_t speedfactor1 = beatsin16(3, 179, 269); uint16_t speedfactor2 = beatsin16(4, 179, 269); uint32_t deltams1 = (deltams * speedfactor1) / 256; uint32_t deltams2 = (deltams * speedfactor2) / 256; uint32_t deltams21 = (deltams1 + deltams2) / 2; sCIStart1 += (deltams1 * beatsin88(1011,10,13)); sCIStart2 -= (deltams21 * beatsin88(777,8,11)); sCIStart3 -= (deltams1 * beatsin88(501,5,7));
sCIStart4 -= (deltams2 * beatsin88(257,4,6));

// Clear out the LED array to a dim background blue-green
fill_solid( leds, NUM_LEDS, CRGB( 2, 6, 10));

// Render each of four layers, with different scales and speeds, that vary over time
pacifica_one_layer( pacifica_palette_1, sCIStart1, beatsin16( 3, 11 * 256, 14 * 256), beatsin8( 10, 70, 130), 0-beat16( 301) );
pacifica_one_layer( pacifica_palette_2, sCIStart2, beatsin16( 4, | 6 * 256,
9 * 256), beatsin8( 17, 40, | 80), beat16( 401) );
pacifica_one_layer( pacifica_palette_3, sCIStart3, 6 * 256, beatsin8( 9, 10,38), 0-beat16(503));

pacifica_one_layer( pacifica_palette_3, sCIStart4, 5 * 256, beatsin8( 8, 10,28), beat16(601));

// Add brighter 'whitecaps' where the waves lines up more pacifica_add_whitecaps();

// Deepen the blues and greens a bit pacifica_deepen_colors();
}

// Add one layer of waves into the led array
void pacifica_one_layer( CRGBPalette16& p, uint16_t cistart, uint16_t wavescale, uint8_t bri, uint16_t ioff)
{
uint16_t ci = cistart;
uint16_t waveangle = ioff;
uint16_t wavescale_half = (wavescale / 2) + 20; for( uint16_t i = 0; i < NUM_LEDS; i++) {
waveangle += 250;
uint16_t s16 = sin16( waveangle ) + 32768;
uint16_t cs = scale16( s16 , wavescale_half ) + wavescale_half; ci += cs;
uint16_t sindex16 = sin16( ci) + 32768;
uint8_t sindex8 = scale16( sindex16, 240);
CRGB c = ColorFromPalette( p, sindex8, bri, LINEARBLEND); leds[i] += c;
}
}

// Add extra 'white' to areas where the four layers of light have lined up brightly
void pacifica_add_whitecaps()
{
uint8_t basethreshold = beatsin8( 9, 55, 65); uint8_t wave = beat8( 7 );

for( uint16_t i = 0; i < NUM_LEDS; i++) {
uint8_t threshold = scale8( sin8( wave), 20) + basethreshold; wave += 7;
uint8_t l = leds[i].getAverageLight();
if( l > threshold) {
uint8_t overage = l - threshold;
uint8_t overage2 = qadd8( overage, overage);
leds[i] += CRGB( overage, overage2, qadd8( overage2, overage2)); }
}
}

// Deepen the blues and greens
void pacifica_deepen_colors()
{
for( uint16_t i = 0; i < NUM_LEDS; i++) { leds[i].blue = scale8( leds[i].blue, 145);

leds[i].green= scale8( leds[i].green, 200); leds[i] |= CRGB( 2, 5, 7);
}
}

// This function draws rainbows with an ever-changing, // widely-varying set of parameters.
void pride()
{
static uint16_t sPseudotime = 0; static uint16_t sLastMillis = 0;
static uint16_t sHue16 = 0;

uint8_t sat8 = beatsin88( 87, 220, 250);
uint8_t brightdepth = beatsin88( 341, 96, 224);
uint16_t brightnessthetainc16 = beatsin88( 203, (25 * 256), (40 * 256)); uint8_t msmultiplier = beatsin88(147, 23, 60);

uint16_t hue16 = sHue16;//gHue * 256;
uint16_t hueinc16 = beatsin88(113, 1, 3000);

uint16_t ms = millis();
uint16_t deltams = ms - sLastMillis ; sLastMillis = ms;
sPseudotime += deltams * msmultiplier; sHue16 += deltams * beatsin88( 400, 5,9); uint16_t brightnesstheta16 = sPseudotime;

for( uint16_t i = 0 ; i < NUM_LEDS; i++) { hue16 += hueinc16;
uint8_t hue8 = hue16 / 256;
brightnesstheta16 | += brightnessthetainc16;
uint16_t b16 = sin16( brightnesstheta16 | ) + 32768;

uint16_t bri16 = (uint32_t)((uint32_t)b16 * (uint32_t)b16) / 65536; uint8_t bri8 = (uint32_t)(((uint32_t)bri16) * brightdepth) / 65536; bri8 += (255 - brightdepth);

CRGB newcolor = CHSV( hue8, sat8, bri8);

uint16_t pixelnumber = i;
pixelnumber = (NUM_LEDS-1) - pixelnumber;

nblend( leds[pixelnumber], newcolor, 64); }
}

void twinkle() {
// Set a random LED to a random color
leds[random(NUM_LEDS)] = CRGB(random(0,255), random(0,255), random(0,255));

// Fade out all LEDs
for (int i = 0; i < NUM_LEDS; i++) { leds[i].fadeToBlackBy(20);
}
}

// List of patterns to cycle through. Each is defined as a separate function below.
typedef void (*SimplePatternList[])();
SimplePatternList gPatterns = { rainbow, rainbowWithGlitter, confetti, sinelon, juggle, bpm };

uint8_t gCurrentPatternNumber = 0; // Index number of which pattern is current
uint8_t gHue = 0; // rotating "base color" used by many of the patterns

#define ARRAY_SIZE(A) (sizeof(A) / sizeof((A)[0]))

void nextPattern()
{
// add one to the current pattern number, and wrap around at the end gCurrentPatternNumber = (gCurrentPatternNumber + 1) % ARRAY_SIZE( gPatterns);
}

void rainbow()
{
// FastLED's built-in rainbow generator fill_rainbow( leds, NUM_LEDS, gHue, 7); }

void rainbowWithGlitter()
{
// built-in FastLED rainbow, plus some random sparkly glitter rainbow();
addGlitter(80);
}

void addGlitter( fract8 chanceOfGlitter)
{
if( random8() < chanceOfGlitter) {
leds[ random16(NUM_LEDS) ] += CRGB::White; }
}

void confetti()
{
// random colored speckles that blink in and fade smoothly fadeToBlackBy( leds, NUM_LEDS, 10);
int pos = random16(NUM_LEDS);

leds[pos] += CHSV( gHue + random8(64), 200, 255); }

void sinelon()
{
// a colored dot sweeping back and forth, with fading trails fadeToBlackBy( leds, NUM_LEDS, 20);
int pos = beatsin16( 13, 0, NUM_LEDS-1 );
leds[pos] += CHSV( gHue, 255, 192);
}

void bpm()
{
// colored stripes pulsing at a defined Beats-Per-Minute (BPM) uint8_t BeatsPerMinute = 62;
CRGBPalette16 palette = PartyColors_p;
uint8_t beat = beatsin8( BeatsPerMinute, 64, 255);
for( int i = 0; i < NUM_LEDS; i++) { //9948
leds[i] = ColorFromPalette(palette, gHue+(i*2), beat-gHue+(i*10)); }
}

void juggle() {
// eight colored dots, weaving in and out of sync with each other fadeToBlackBy( leds, NUM_LEDS, 20);
uint8_t dothue = 0;
for( int i = 0; i < 8; i++) {
leds[beatsin16( i+7, 0, NUM_LEDS-1 )] |= CHSV(dothue, 200, 255); dothue += 32;
}
}
// This function sets up the ledsand tells the controller about them void setup() {

// Initialize the ultrasonic sensor pins
//pinMode(trigPin, OUTPUT); //pinMode(echoPin, INPUT);

// Initialize the serial communication
Serial.begin(9600);
btSerial.begin(9600); // initialize Bluetooth communication

// sanity check delay - allows reprogramming if accidently blowing power w/leds
delay(2000);
pinMode(bottonPin,INPUT);
// Uncomment/edit one of the following lines for your leds arrangement. // ## Clockless types ##

FastLED.addLeds<WS2811, DATA_PIN, RGB>(leds, NUM_LEDS);
// ## Clocked (SPI) types ##
pixels.begin(); // Initialize LED strip
}

// This function runs over and over, and is where you do the magic to light // your leds.
int t=6;
void loop() {

if(Serial.available() > 0) {3333333330000000000000006 t = Serial.read();
Serial.print(t);
Serial.print("\n"); | }

bt=digitalRead(bottonPin); if (bt==1){
if (t==9){t=1;}
else{t++;}
delay(500);}

if (t==1){

// Move a single white led
for(int whiteLed = 0; whiteLed < NUM_LEDS; whiteLed = whiteLed + 1) { // Turn our current led on to white, then show the leds leds[whiteLed] = CRGB(2, 248, 35);

// Show the leds (only one of which is set to white, from above) FastLED.show();

// Wait a little bit
delay(10);

// Turn our current led back to black for the next loop around leds[whiteLed] = CRGB::Black;}}

else if(t==2)
{ //twinkle
twinkle();
FastLED.show();
FastLED.delay(1000 / FRAMES_PER_SECOND); }

else if(t==5)
{
/// | Pacifica
EVERY_N_MILLISECONDS( 20) {
| pacifica_loop();
| FastLED.show();
}
}

else if(t==3){

//Add entropy to random number generator; we use a lot of it. // random16_add_entropy( random());

Fire2012(); // run simulation frame

FastLED.show(); // display this frame FastLED.delay(1000 / FRAMES_PER_SECOND);

}

else if(t==4)
{ | //Pride2015
| pride(); FastLED.show();

}

else if(t==6){
// | rainbow
| static uint8_t hue = 0;
| // Fill the entire strip with a rainbow of colors
| for (int i = 0; i < NUM_LEDS; i++) {
| leds[i] = CHSV(hue + (i * 255 / NUM_LEDS), 255, 255);
}
| // Move the rainbow along the strip
| for (int i = 0; i < NUM_LEDS; i++) {
| leds[i] = leds[(i + 1) % NUM_LEDS];
}
| FastLED.show();
| hue++;
}

else if(t==7){

| // DemoReel100.
| // Call the current pattern function once, updating the 'leds' array
| gPatterns[gCurrentPatternNumber]();
| // send the 'leds' array out to the actual LED strip
| FastLED.show();
| // insert a delay to keep the framerate modest
| FastLED.delay(1000/FRAMES_PER_SECOND);
| // do some periodic updates
| EVERY_N_MILLISECONDS( 20 ) { gHue++; }
// slowly cycle the "base color" through the rainbow
| EVERY_N_SECONDS( 10 ) { nextPattern(); }

// change patterns periodically }

else if(t==8){

ChangePalettePeriodically();

static uint8_t startIndex = 0;
startIndex = startIndex + 1; /* motion speed */

FillLEDsFromPaletteColors( startIndex);

FastLED.show();
FastLED.delay(1000 / UPDATES_PER_SECOND);}

else if (t==9)
{
int sensitivity = map(analogRead(A6), 0, 1023, 50, 100); Serial.println(analogRead(A6));

for (int i = 0; i < 64; i++)
{
realComponent[i] = analogRead(micPin) / sensitivity; // Read from the microphone sensor pin
imagComponent[i] = 0;
}

FFT.Windowing(realComponent, 64, FFT_WIN_TYP_HAMMING, FFT_FORWARD); FFT.Compute(realComponent, imagComponent, 64, FFT_FORWARD); FFT.ComplexToMagnitude(realComponent, imagComponent, 64);

for (int i = 0; i < 16; i++)
{
int ledIndex = i % 4 * 4 + i / 4;
realComponent[i] = constrain(realComponent[i], 0, 80); realComponent[i] = map(realComponent[i], 0, 80, 0, 7); index = realComponent[i];
c = spectralHeight[index];

led.setPixelColor(ledIndex, c, 0, 0); // Set RGB values accordingly (e.g., Red)
led.setPixelColor(ledIndex+16, c, 0, 0); led.setPixelColor(ledIndex+32, c, 0, 0);

}
led.show();
}
pixels.show();
}

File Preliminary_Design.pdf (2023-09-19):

DEPARTMENT OF ELECTRONIC AND TELECOMMUNICATION ENGINEERING

UNIVERSITY OF MORATUWA
EN2160: ENGINEERING DESIGN REALIZATION


## Report – Preliminary Design

## Mood Lamp

MADUSAN A.K.C.S.
200366E

14st June 2023

## Schematic and Solidworks


## Implemented SolidWorks


Problems Identified

1. Schematic Design:
- Status box filling: Ensure that the status box provides clear and concise information about the lamp's current mode or state.
- Naming components from top to bottom: Organize and label components in a logical and sequential manner to facilitate easy identification and troubleshooting.
- Minimizing wire usage: Utilize net labels to reduce the need for excessive wiring, improving the overall aesthetics and functionality of the lamp.

### 2. Enclosure Moldability

- Draft angle analysis: Assess the enclosure design for appropriate draft angles to enable smooth ejection from the mold during the manufacturing process
- Design for moldability: Optimize the lamp's design to ensure it can be produced using injection molding, taking into account factors such as wall thickness, undercuts, and parting lines.
- Injection molding process: Familiarize yourself with the injection molding process and collaborate with manufacturers to ensure the design aligns with their capabilities and requirements.

### 3. Appearance for Marketing:

- Importance of final appearance: Recognize that the visual appeal of the mood lamp is crucial for attracting customers and creating a desirable product
- Attractiveness through color and texture: Select colors and surface textures that enhance the lamp's aesthetic appeal and align with the desired mood or ambiance.

### 4. User Need Analysis:

- Gathering user feedback: Conduct surveys, interviews, or user testing sessions to understand users' preferences, expectations, and pain points related to mood lamps.
- User feedback analysis methods: Utilize qualitative and quantitative analysis techniques to interpret and prioritize user feedback, identifying key areas for improvement or additional features.

### 5. Design Cycle Implementation:

- Proper design process: Follow a systematic design process, including stages such as research, ideation, concept development, prototyping, testing, and iteration.
- Product improvement through design cycles: Use feedback from each design iteration to refine and enhance the mood lamp, ensuring it meets user requirements and resolves identified issues.

### 6. Product Manual and Documentation:

- User manual: Create a comprehensive user manual that provides clear instructions on setting up, operating, and maintaining the mood lamp, including safety guidelines and troubleshooting tips.
- Maintenance manual: Develop a separate maintenance manual that outlines regular care, cleaning, and replacement procedures to prolong the lamp's lifespan and ensure optimal performance.
- Proper documentation: Maintain detailed records of the design process, including specifications, schematics, BOM (Bill of Materials), manufacturing guidelines, and any design changes made throughout the development of the mood lamp. This documentation helps with future reference, product support, and potential updates.

### Problems and Improvements Provided by Group Members

Problems Identified:

1. Size: The size of the mood lamp may be a concern, as users often prefer compact and visually appealing designs. Finding ways to minimize the overall size of the lamp while maintaining its functionality is essential.
2. External wire minimization: Excessive external wiring can detract from the aesthetics and convenience of the mood lamp. Minimizing the number of visible wires or finding wireless solutions will enhance the user experience.
3. Analog circuit accuracy: The accuracy of the analog circuitry in the mood lamp is crucial for producing the desired lighting effects and color accuracy. Any inaccuracies or variations can negatively impact the overall moodenhancing experience.

Improvements

1. Using microphones to capture ambient noise: Incorporating microphones into the mood lamp can enable it to react to the surrounding environment. By capturing ambient noise levels, the lamp can adjust its lighting patterns or colors accordingly, creating a more immersive and responsive experience.
2. Digital noise-canceling circuit: Implementing a digital noise-canceling circuit can help reduce any unwanted electrical noise or interference that may affect the performance of the mood lamp. This will result in cleaner and more accurate lighting effects.
3. Efficient LED driver circuit: Designing an efficient LED driver circuit can optimize power consumption and minimize heat generation. This will ensure that the mood lamp operates reliably while maintaining low energy consumption and extended lifespan for the LEDs.

Problems Identified:

1. Size: The user wants to minimize the size of the device as much as possible.
2. Attractiveness: The user wants the device to be visually appealing.
3. External wire minimization: The user wants to minimize the number of external wires for a cleaner look.

Improvements:

1. Using Mic Sensor LED music visualization; A music visualizer effect is a feature that allows the mood lamp's LED strip to synchronize with the beat and rhythm of the music being played. When the visualizer is activated, the LED strip will change colors and patterns in time with the music, creating a dynamic and immersive lighting experience.
2. Make it more user-friendly shape: Designing the device with a user-friendly shape can enhance its appeal. Consider a shape that is ergonomic, easy to hold or interact with, and aesthetically pleasing. This can improve the overall user experience and make it more inviting to use.

### Schematic and Solidworks of Improved Design


Schematic

## SolidWorks

Assembly Encloser


Base part Sketch

Base part


Draft Analysis


Mold part

Cube part Sketch

Cube part


Stand part Sketch | Stand part

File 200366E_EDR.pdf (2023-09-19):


Department of Electronic and Telecommunication Engineering
University of Moratuwa
Product Specifications and extra features EN2160- Electronic Design Realization 200366E A . K . C. S. MADUSAN


# Mood lamp

Mood lamps are popular for creating a specific ambiance in a room. They come in a variety of designs, sizes, colors, and brightness levels, making it easy to find one that fits your needs. Mood lamps can be used in many settings, such as bedrooms, living rooms, and offices, and are often used to create a relaxing or calming atmosphere.

## Product Specifications

1) Size: This mood lamp comes in a tabletop model
2) Color: A mood lamp can be programmed to emit different colors of light, which can help

create a specific mood or atmosphere. It may have a range of preset colors or may allow

you to customize the color using a remote control or smartphone app.

3) Brightness: The brightness of a mood lamp can also be adjusted to suit your needs.
4) LED Pattern and Design: Mood lamps come in a range of 8 to 12 LED patterns, each with

unique style and features, so you can choose the one that best fits your mood and

preferences.

5) Power source: Mood lamp powered by rechargeable batteries.

## Extra Features

## Remote control


if you connect a mood lamp to your smartphone or computer via

Bluetooth, you can control it remotely using a dedicated app or a

web interface. Bluetooth is a wireless technology that allows

devices to communicate with each other over short distances. By

pairing your mood lamp with your smartphone or computer via

Bluetooth, you can control various settings such as the color,

brightness, and lighting effects from the app

## LED music visualizer


A music visualizer effect is a feature that allows the mood

lamp's LED strip to synchronize with the beat and rhythm of

the music being played. When the visualizer is activated,

the LED strip will change colors and patterns in time with

the music, creating a dynamic and immersive lighting

experience.

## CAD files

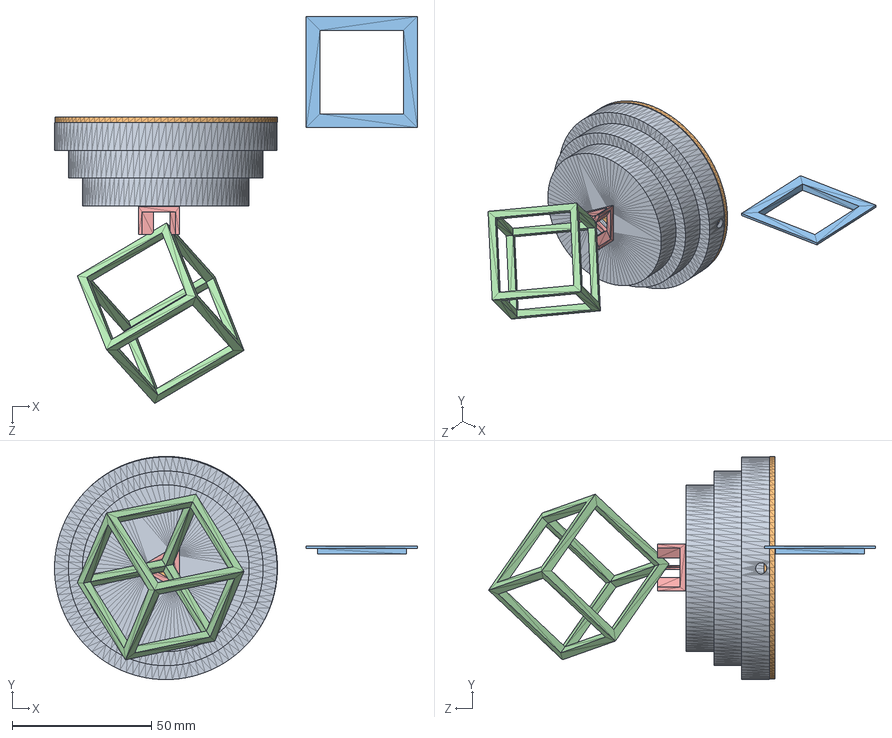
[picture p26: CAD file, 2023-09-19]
Solidworks/FINAL.SLDASM
130.5 x 80.2 x 139.1 mm
Base
cover
holder
skelton
stand

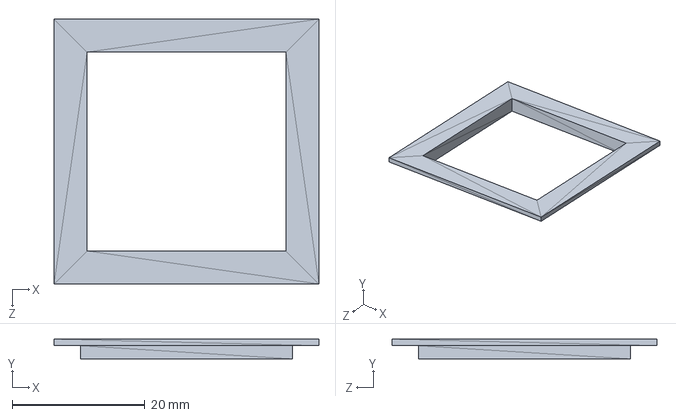
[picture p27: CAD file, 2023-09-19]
Solidworks/parts/holder.SLDPRT
40.0 x 3.00 x 40.0 mm

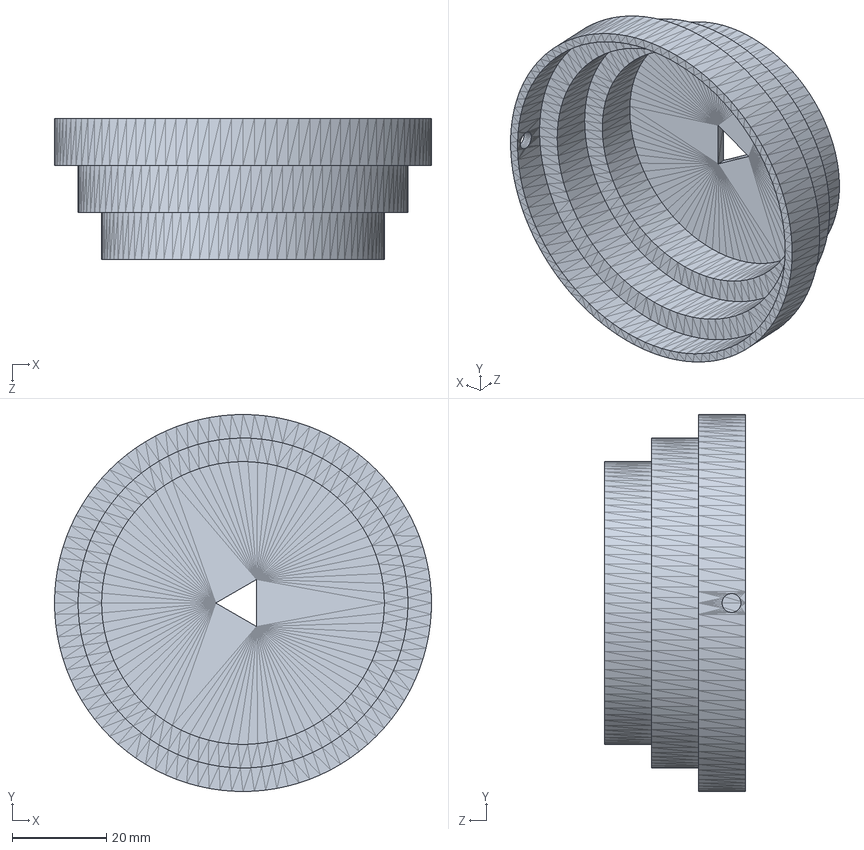
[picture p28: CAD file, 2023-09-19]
Solidworks/parts/Base.SLDPRT
80.0 x 80.0 x 30.0 mm

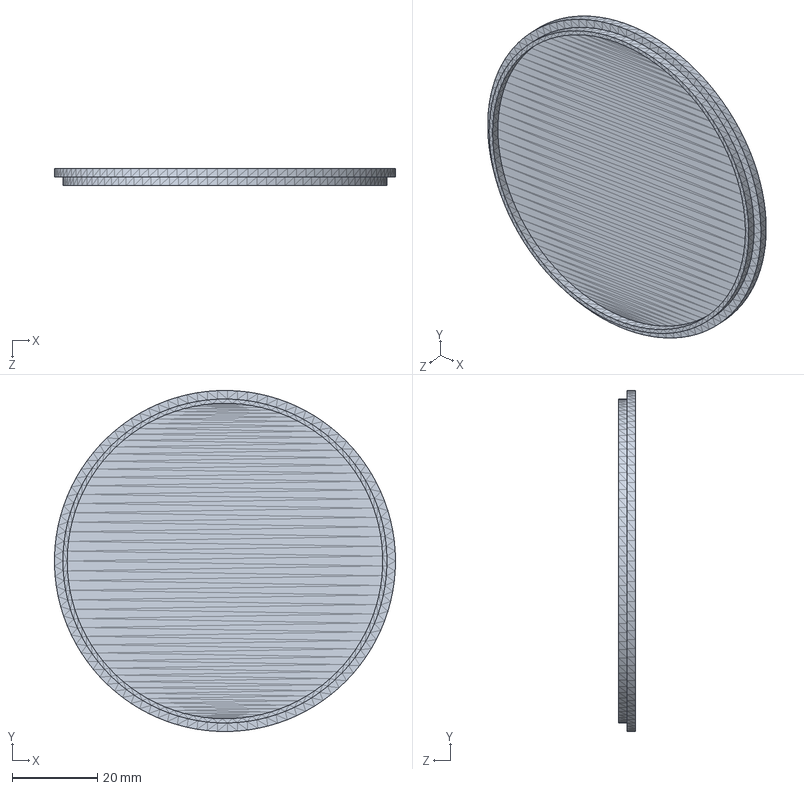
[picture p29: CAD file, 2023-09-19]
Solidworks/parts/cover.SLDPRT
80.0 x 80.0 x 4.00 mm

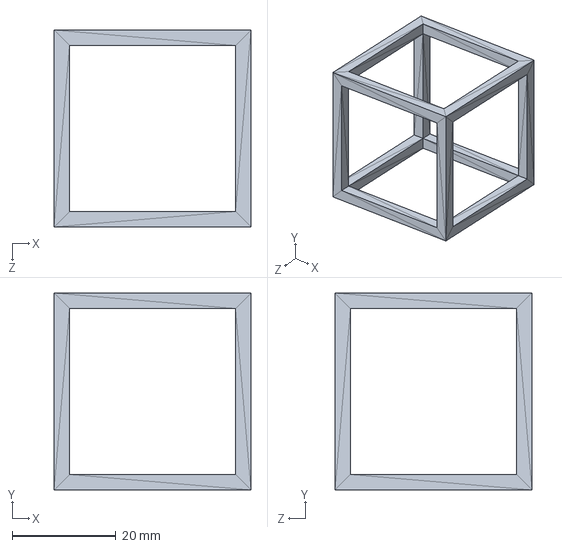
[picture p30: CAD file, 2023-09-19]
Solidworks/parts/skelton.SLDPRT
38.0 x 38.0 x 38.0 mm

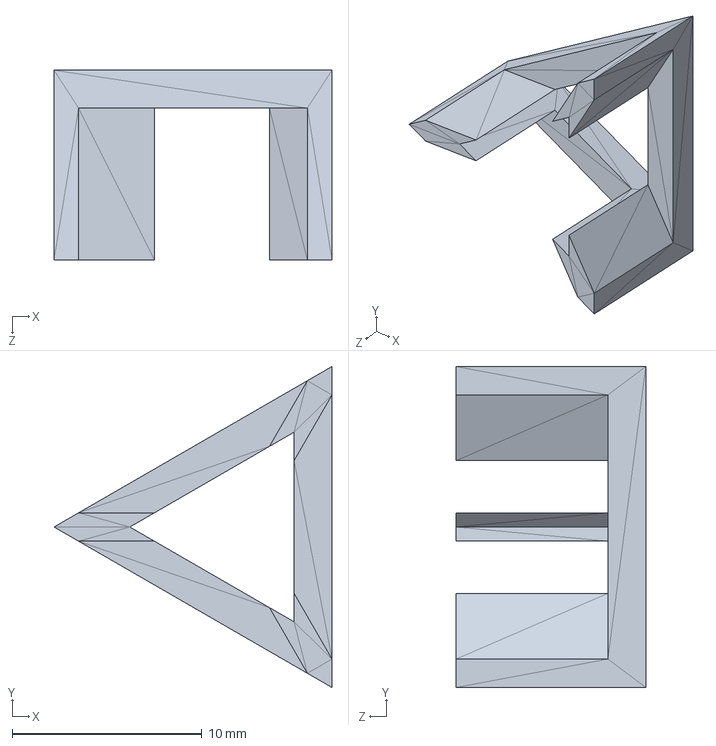
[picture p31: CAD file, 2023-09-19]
Solidworks/parts/stand.SLDPRT
14.7 x 16.9 x 10.0 mm
